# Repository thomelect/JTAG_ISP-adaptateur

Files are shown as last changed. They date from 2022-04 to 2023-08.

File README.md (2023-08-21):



<div align="center">
<h3 align="center">&#9889; Adaptateur JTAG vers ISP &#9889;</h3>
<a href="docs/img/JTAG_ISP-t.png">
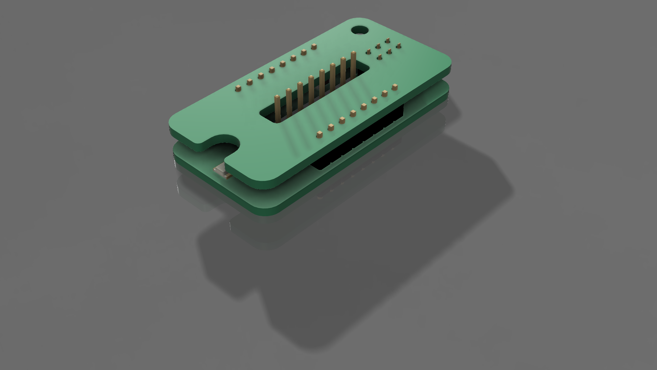
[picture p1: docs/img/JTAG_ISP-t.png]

</a>
<a href="docs/img/JTAG_ISP-b.png">
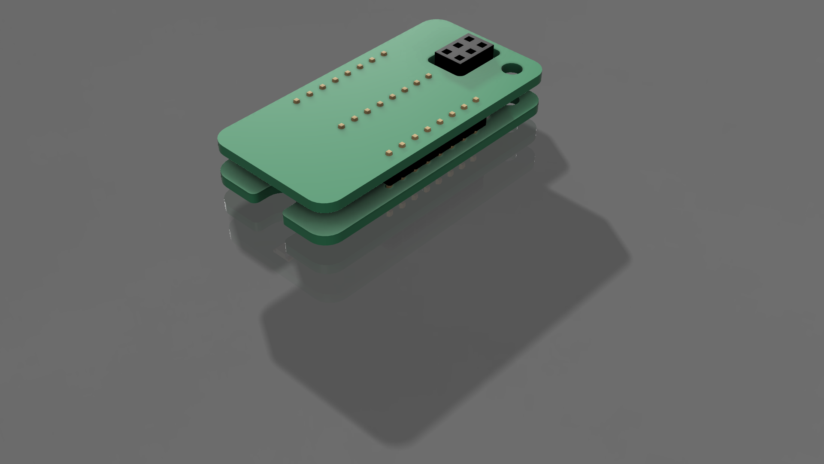
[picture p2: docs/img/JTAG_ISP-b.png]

</a>
<br>
<br>
<p align="center">Adaptateur compact utilisé pour connecteur un <a href="https://www.microchip.com/en-us/development-tool/PG164140">PICkit4 (JTAG)</a> au Arduino micro (ISP).</p>
</div>

<!-- TABLE DES MATIÈRES -->

---

<details>
<summary>Table des matières</summary>
<ol>
    <li>
        <a href="#apropos">À propos</a>
        <ul>
            <li><a href="#creation">Création</a></li>
            <ul>
                <li><a href="#creation_logiciels">Logiciels</a></li>
                <li><a href="#creation_fabrication-pcb">Fabrication PCB</a></li>
            </ul>
        </ul>
    </li>
    <li>
        <a href="#pour-debuter">Pour débuter</a>
        <ul>
            <li><a href="#prerequis">Prérequis</a>
            <ul>
                <li><a href="#prerequis_outils">Outils</a></li>
                <li><a href="#prerequis_bom">BOM</a></li>
            </ul>
            <li><a href="#assemblage">Assemblage</a></li>
        </ul>
    </li>
    <li><a href="#utilisation">Utilisation</a></li>
    <li><a href="#licence">Licence</a></li>
    <li><a href="#contacts">Contacts</a></li>
    <li><a href="#ressources">Ressources</a></li>
    <li><a href="#modele-readme">Modèle README</a></li>
</ol>
</details>

---

<!-- À-PROPOS -->

## À propos

Ce produit est utilisé pour programmer un microcontrôleur AVR avec un [PICkit4](https://www.microchip.com/en-us/development-tool/PG164140) sans l'utiliser connecté par JTAG. Il es alors possible d'utiliser le PICkit4 comme un [AVRISP MKII](https://www.microchip.com/en-us/development-tool/ATAVRISP2). Bien que l'utilisation du PICkit4 connecté en JTAG est utile pour le débogage des microcontrôleurs, lorsque le but est seulement de programmer et non de déboguer, il est plus rapide d'utiliser l'ISP puisque la connexion que requiert la connexion par JTAG nécessite plus de manipulations. Ce projet d'adaptateur parmet d'éviter l'utilisation de fils comme interface entre le PICkit4 et le microcontrôleur.

<p align="right">(<a href="#top">Haut de la page</a>)</p>

---

<!-- CRÉATION -->

### Création

- #### Logiciels

<ul>
<i><strong>👉 Design PCB</strong></i>
<ul>
<li>
<a href="https://www.kicad.org/">KiCad</a>
</li>
</ul>
<i><strong>👉 Export Fusion 360</strong></i>
<ul>
<li>
<a href="https://www.freecadweb.org/">FreeCAD</a>
</li>
<li>
<a href="https://wiki.freecadweb.org/KicadStepUp_Workbench/it">KiCad StepUp</a>
</li>
</ul>
<i><strong>👉 Rendu 3D</strong></i>
<ul>
<li>
<a href="https://www.autodesk.ca/fr/products/fusion-360">Fusion 360</a>
</li>
</ul>
</ul>

- #### Fabrication PCB

    - [PCBWay](https://www.pcbway.com/)
    - [JLCPSB](https://jlcpcb.com/)

<p align="right">(<a href="#top">Haut de la page</a>)</p>

---

<!-- POUR DÉBUTER -->

## Pour débuter

Les deux PCB ont été créés dans deux projets KiCad séparés. JTAG_ISP-ISP contient la partie du projet sur lequel le connecteur ISP est soudé alors que JTAG_ISP-HDR contient la partie du projet sur lequel le connecteur JTAG est soudé. Les deux PCB sont contenus dans le projet JTAG_ISP-BOTH.

<p align="right">(<a href="#top">Haut de la page</a>)</p>

---

<!-- PRÉREQUIS -->

### Prérequis

- #### Outils

  - [WE1010;](https://www.weller-tools.com/we1010na/)
  - [OMNIFIXO](https://omnifixo.com/)

- #### BOM

<table>
<tr>
<th><i>Adaptateur PinOut</i></th>
</tr>
<tr>
<td>

| Qty | Reference(s) | Value |
| :-: | :--- | --- |
|  1  | C1 | 100nF |
|  1  | J1 | PinSocket_2x03_P2.54mm |
|  2  | J2, J3 | PinHeader_1x08_P2.54mm |

</td>
</tr>
</table>
<table>
<tr>
<th><i>Adaptateur PinOut</i></th>
</tr>
<tr>
<td>

| Qty | Reference(s) | Value |
| :-: | :--- | --- |
|  1  | C1 | 100nF |
|  1  | D1 | LED |
|  2  | J1, J2 | PinSocket_2x03_P2.54mm |
|  1  | JTAG1 | PinHeader_1x08_P2.54mm |
|  1  | R1 | 100R |

</td>
</tr>
</table>

<p align="right">(<a href="#top">Haut de la page</a>)</p>

---

<!-- ASSEMBLAGE -->

### Assemblage

Il est seulement nécessaire de souder ensemble les composants sur le bon PCB et l'adaptateur est prêt à être utilisé!

<p align="right">(<a href="#top">Haut de la page</a>)</p>

---

<!-- UTILISATION -->

## Utilisation

Ce produit est utilisé pour programmer un microcontrôleur AVR avec un PICkit4 sans avoir à l'utiliser en le connectant par JTAG. Connectez simplement l'adapteteur sur le microcontrôleur et connectez ensuite le PICkit4 à l'adaptateur!

<table>
<tr>
<th><i>ISP sans adaptateur</i></th>
<th><i>ISP avec adaptateur</i></th>
</tr>
<tr>
<td>
<a href="docs/img/utilisationAvant.jpg">
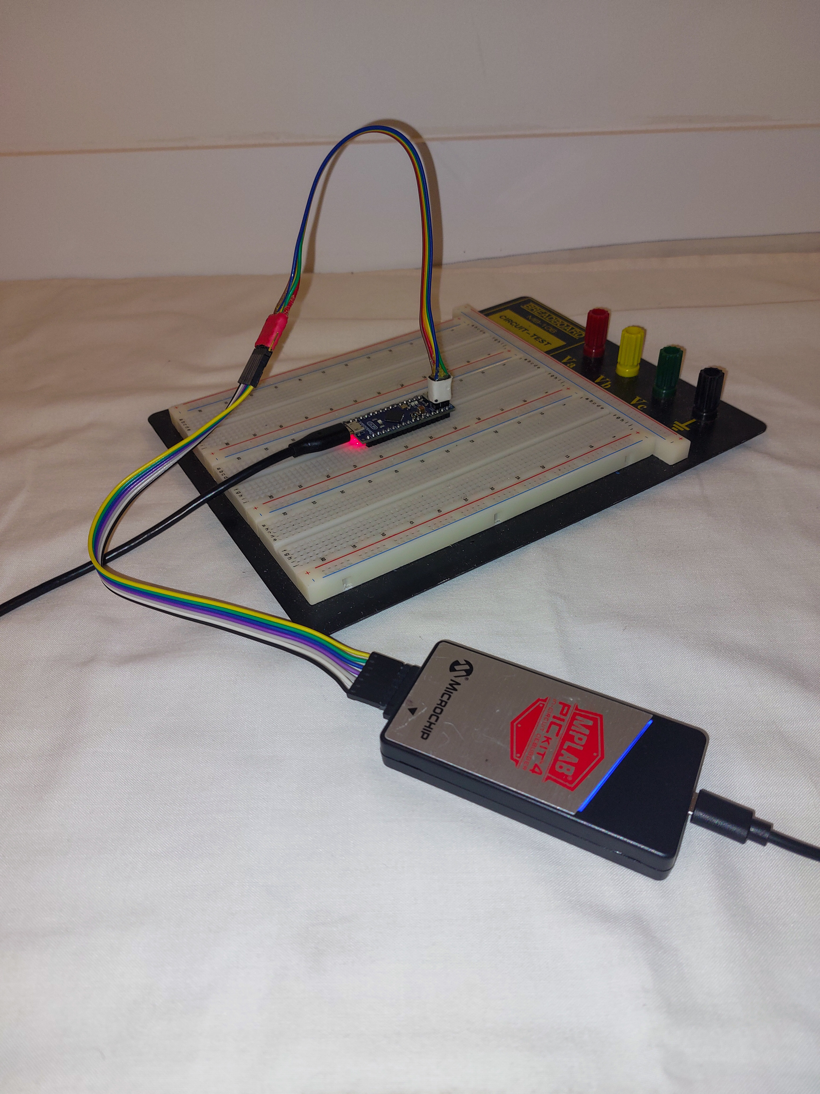
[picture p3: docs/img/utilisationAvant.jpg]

</a>
</td>
<td>
<a href="docs/img/utilisationApres.jpg">
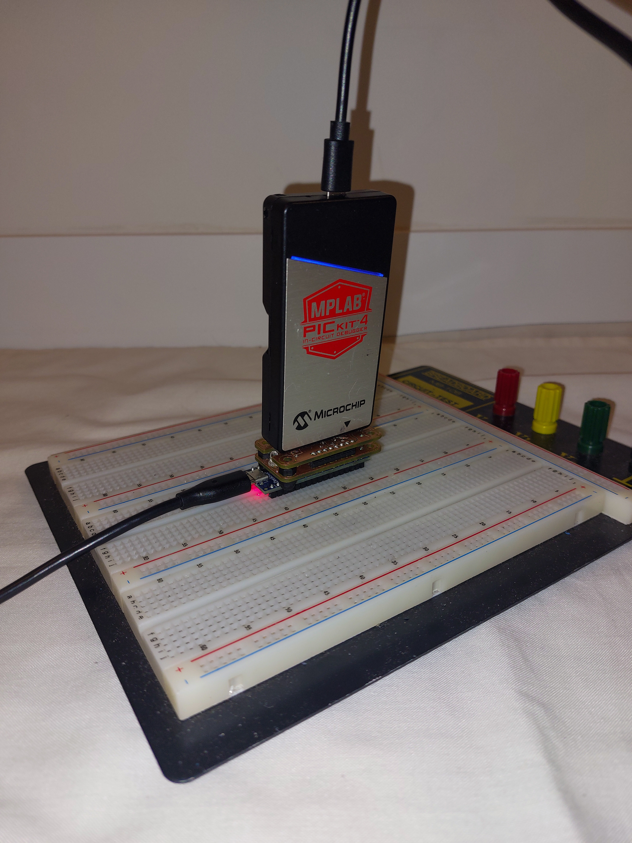
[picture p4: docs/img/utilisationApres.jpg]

</a>
</td>
</tr>
</table>

<p align="right">(<a href="#top">Haut de la page</a>)</p>

---

<!-- LICENCE -->

## Licence

Copyright 2022 Thomas Desrosiers

Licensed under the Apache License, Version 2.0 (the "License");
you may not use this file except in compliance with the License.
You may obtain a copy of the License at

       http://www.apache.org/licenses/LICENSE-2.0

Unless required by applicable law or agreed to in writing, software
distributed under the License is distributed on an "AS IS" BASIS,
WITHOUT WARRANTIES OR CONDITIONS OF ANY KIND, either express or implied.
See the License for the specific language governing permissions and
limitations under the License.

<p align="right">(<a href="#top">Haut de la page</a>)</p>

---

<!-- CONTACTS -->

## Contacts

<ul>
<i><strong>👉 GitHub</strong></i>
<ul>
<li>
<a href="https://github.com/thomelect" style="vertical-align:middle">thomelect</a>
</li>
<li>
<a href="https://github.com/thomelect/JTAG_ISP-adaptateur/" style="vertical-align:middle">Projet lumiereGarage</a>
</li>
</ul>
</ul>

<p align="right">(<a href="#top">Haut de la page</a>)</p>

---

<!-- RESSOURCES -->

## Ressources

<details>
<summary>PinOut</summary>
<table>
<tr>
<th><i>PICkit4</i></th>
<th><i>JTAP PinOut</i></th>
<th><i>ARDUINO ISP PinOut
<i></th>
</tr>
<tr>
<td>

<table>
<tr>
<th>Pin #</th>
<th>PICkit4</th>
</tr>
<tr>
<td>1</td>
<td>Vpp/NMCLR</td>
</tr>
<tr>
<td>2</td>
<td>VDD</td>
</tr>
<tr>
<td>3</td>
<td>GND</td>
</tr>
<tr>
<td>4</td>
<td>PGD</td>
</tr>
<tr>
<td>5</td>
<td>PGC</td>
</tr>
<tr>
<td>6</td>
<td>AUX</td>
</tr>
<tr>
<td>7</td>
<td>TDI</td>
</tr>
<tr>
<td>8</td>
<td>TMS</td>
</tr>
</table>

</td>
<td>

<table style="vertical-align:top">
<tr>
<th>Pin #</th>
<th>JTAG</th>
</tr>
<tr>
<td>1</td>
<td>-</td>
</tr>
<tr>
<td>2</td>
<td>VDD</td>
</tr>
<tr>
<td>3</td>
<td>GND</td>
</tr>
<tr>
<td>4</td>
<td>TDO</td>
</tr>
<tr>
<td>5</td>
<td>TCK</td>
</tr>
<tr>
<td>6</td>
<td>NRESET</td>
</tr>
<tr>
<td>7</td>
<td>TDI</td>
</tr>
<tr>
<td>8</td>
<td>TMS</td>
</tr>
</table>

</td>
<td>

<table>
<tr>
<th>Pin #</th>
<th>ISP</th>
</tr>
<tr>
<td>1</td>
<td>CIPO (MISO)</td>
</tr>
<tr>
<td>2</td>
<td>VCC</td>
</tr>
<tr>
<td>3</td>
<td>SCK</td>
</tr>
<tr>
<td>4</td>
<td>COPI (MOSI)</td>
</tr>
<tr>
<td>5</td>
<td>RESET</td>
</tr>
<tr>
<td>6</td>
<td>GND</td>
</tr>
</table>

</td>
</tr>
</table>
<table>
<tr>
<th><i>Adaptateur PinOut</i></th>
</tr>
<tr>
<td>

<table>
<tr>
<th>Pin #</th>
<th>JTAG</th>
<th>ISP</th>
</tr>
<tr>
<td>1</td>
<td>-</td>
<td>-</td>
</tr>
<tr>
<td>2</td>
<td>VDD</td>
<td>VCC</td>
</tr>
<tr>
<td>3</td>
<td>GND</td>
<td>GND</td>
</tr>
<tr>
<td>4</td>
<td>TDO</td>
<td>CIPO (MISO)</td>
</tr>
<tr>
<td>5</td>
<td>TCK</td>
<td>SCK</td>
</tr>
<tr>
<td>6</td>
<td>NRESET</td>
<td>RESET#</td>
</tr>
<tr>
<td>7</td>
<td>TDI</td>
<td>COPI (MOSI)</td>
</tr>
<tr>
<td>8</td>
<td>TMS</td>
<td>-</td>
</tr>
</table>

</td>
</tr>
</table>
</details>

<ul>
<li>
<a href="https://docs.arduino.cc/static/59994142e99a42eea5731bf61b08922b/A000053-full-pinout.pdf"
style="vertical-align:middle">Arduino Micro PinOut (Le PinOut est le même pour tout les Arduino).</a>
</li>
<li>
<a href="http://ww1.microchip.com/downloads/en/devicedoc/50002721a.pdf" style="vertical-align:middle">PICkit4
Quick Start Guide.</a>
</li>
</ul>

<p align="right">(<a href="#top">Haut de la page</a>)</p>

---

<!-- MODÈLE README -->

## Modèle README

<a href="https://github.com/othneildrew/Best-README-Template/blob/master/BLANK_README.md">`Template README`</a>

<p align="right">(<a href="#top">Haut de la page</a>)</p>

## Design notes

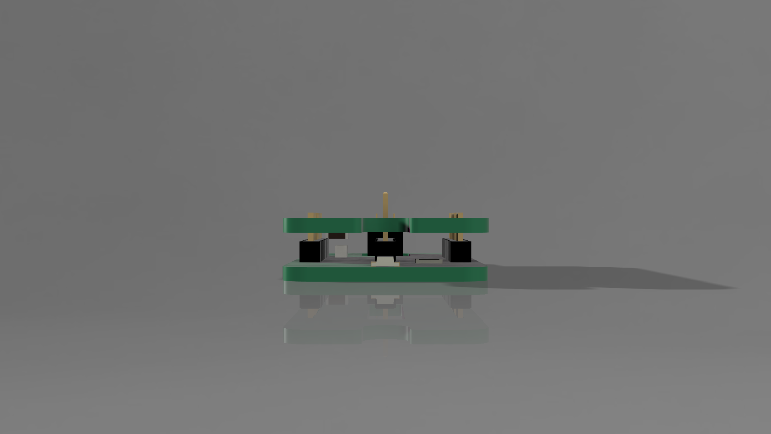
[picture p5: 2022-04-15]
docs/img/JTAG_ISP-f.png

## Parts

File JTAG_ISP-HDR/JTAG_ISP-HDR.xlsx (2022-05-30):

Item | Qty | Reference(s) | Value | LibPart | Footprint | Datasheet
1 | 1 | C1 | 100nF | Device:C | Capacitor_SMD:C_1206_3216Metric_Pad1.33x1.80mm_HandSolder | ~
2 | 1 | D1 | LED | Device:LED | LED_SMD:LED_1210_3225Metric_Pad1.42x2.65mm_HandSolder | ~
3 | 2 | J1, J2 | Conn_01x08 | Connector_Generic:Conn_01x08 | Connector_PinHeader_2.54mm:PinHeader_1x08_P2.54mm_Vertical | ~
4 | 1 | JTAG1 | PICkit4 | THOMAS_library:PICkit4 | THOMAS_library:PicKit4-2
5 | 1 | R1 | 100 | Device:R_US | Resistor_SMD:R_1206_3216Metric_Pad1.30x1.75mm_HandSolder | ~

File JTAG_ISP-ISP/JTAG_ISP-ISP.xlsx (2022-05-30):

Item | Qty | Reference(s) | Value | LibPart | Footprint | Datasheet
1 | 1 | C1 | 100nF | Device:C | Capacitor_SMD:C_1206_3216Metric_Pad1.33x1.80mm_HandSolder | ~
2 | 1 | J1 | Conn_02x03_Odd_Even | Connector_Generic:Conn_02x03_Odd_Even | Connector_PinSocket_2.54mm:PinSocket_2x03_P2.54mm_Vertical | ~
3 | 2 | J2, J3 | Conn_01x08 | Connector_Generic:Conn_01x08 | Connector_PinHeader_2.54mm:PinHeader_1x08_P2.54mm_Vertical | ~

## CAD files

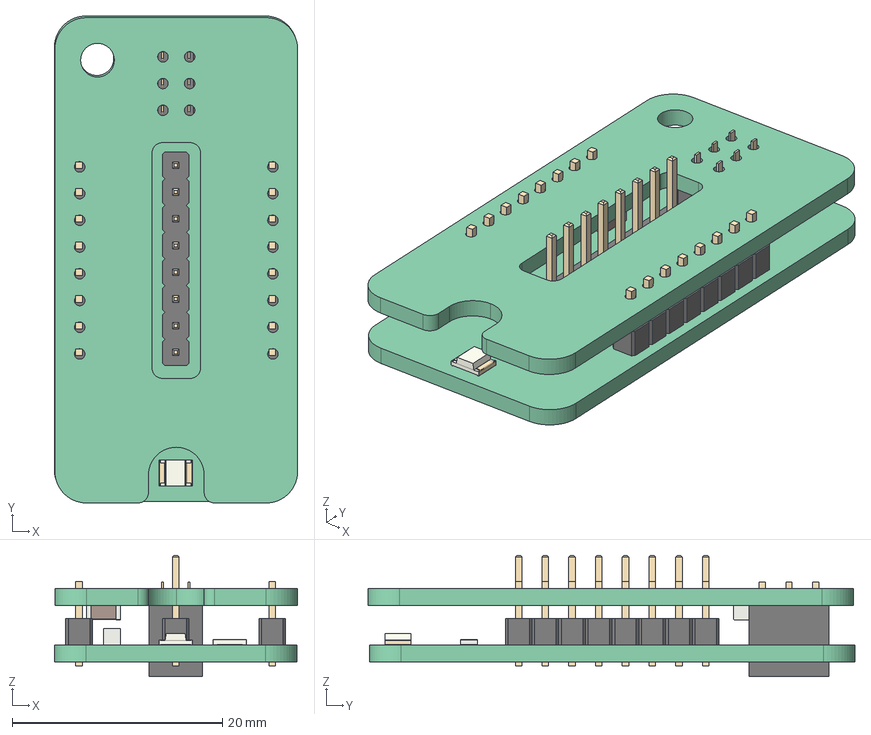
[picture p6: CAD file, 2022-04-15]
docs/3d/JTAG_ISP-3d.step
23.1 x 46.3 x 11.5 mm
Pcb_b0ad
C1_C_1206_3216Metric_8ab35eb3909b
J1_PinSocket_2x03_P254mm_Vertical_11958836bf48
Pcb_3d3b
J2_PinHeader_1x08_P254mm_Vertical_fe993c246832
C1_C_1206_3216Metric_07f5eb895435
J1_PinHeader_1x08_P254mm_Vertical_b79930fb2714
JTAG1_PinHeader_1x08_P254mm_Vertical_10c12ca8a28d
D1_LED_1210_3225Metric_053afcd77527
R1_R_1206_3216Metric_2292a632100f

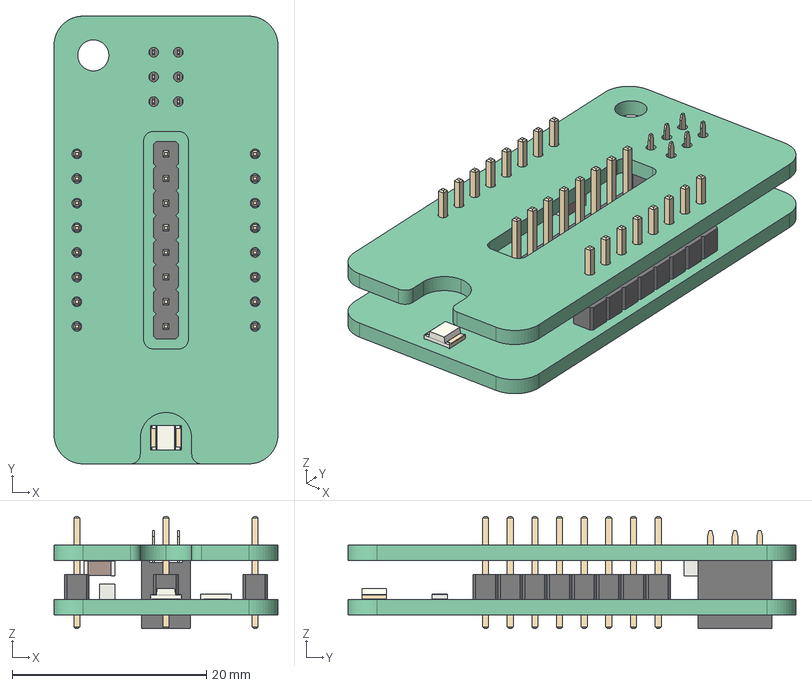
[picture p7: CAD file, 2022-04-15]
docs/3d/JTAG_ISP_3d-base.step
23.1 x 46.1 x 11.5 mm
Pcb_b0ad
C1_C_1206_3216Metric_8ab35eb3909b
J1_PinSocket_2x03_P254mm_Vertical_11958836bf48
Pcb_3d3b
J2_PinHeader_1x08_P254mm_Vertical_fe993c246832
C1_C_1206_3216Metric_07f5eb895435
J1_PinHeader_1x08_P254mm_Vertical_b79930fb2714
JTAG1_PinHeader_1x08_P254mm_Vertical_10c12ca8a28d
D1_LED_1210_3225Metric_053afcd77527
R1_R_1206_3216Metric_2292a632100f

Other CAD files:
docs/3d/JTAG_ISP_3d-base.FCStd

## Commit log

2022-03-15 + Création des deux PCB dans des projets séparés. + Ajout d'un projet dans lequel les deux PCB sont joints. **Le circuit pour l'étage ISP est à vérifier**
    [JTAG_ISP-HDR.kicad_pcb, JTAG_ISP-HDR.kicad_sch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]
2022-03-15 + Ajout d'un trou sur chacun des 2 PCB pour pouvoir y fixer une dragone. + Ajout d'un espace de texte contenant mon nom et la date sur le PCB ISP. + Ajout d'un dossier contenant les fichiers générés 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
    [JTAG_ISP-HDR-B_Cu.gbl, JTAG_ISP-HDR-B_Cu.gbr, JTAG_ISP-HDR-Edge_Cuts.gbr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]
2022-03-15 # [PCB] ~ Modification du PCB pour le projet ISP en fonction des nouvelles connexions sur son schéma. + Ajout de trous aux 4 coins du PCB des 2 projets (ISP & HDR). ~ Augmentation de la taille du PCB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
    # [SCHÉMA]
    ~ Modification du schéma pour le projet ISP basé sur le fil JTAG -> ISP déjà existant.
    + Ajout de texte sur le schéma des 2 projets indiquant le nom des broches sur les headers.
    [JTAG_ISP-HDR-B_Cu.gbl, JTAG_ISP-HDR-B_Cu.gbr, JTAG_ISP-HDR-Edge_Cuts.gbr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]
2022-03-15 + Ajout d'un projet dans lequel les deux PCB sont joints.
    # [PCB]
    + Ajout d'une DEL et de sa résistance en fonction des nouvelles connexions sur son schéma.
    ~ Déplacement du header ISP sur le côté dans le projet ISP afin de moins empiéter sur les circuits autour lorsque le shied est utilisé sur un MCU.
    ~ Rotation du header ISP pour être plus facilement connecté au MCU.
    + Ajout d'une DEL et de sa résistance sur le broche MISO pour pour pouvoir voir quand est-ce qu'une programmation se fait.
    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
    [JTAG_ISP-BOTH.kicad_pcb, JTAG_ISP-BOTH.kicad_sch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]
2022-03-15 - Abandon de la panélisation puisque son utilisation n'est pas pertinante et trop compliquée.
    [JTAG_ISP-HDR-B_Cu.gbl, JTAG_ISP-HDR-Edge_Cuts.gko, JTAG_ISP-HDR-F_Cu.gtl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]
2022-03-16 # [PCB] ~ Augmentation de la largeur des traces et du dégagement des traces à 20 mils.
    [JTAG_ISP-HDR.kicad_pcb, JTAG_ISP-ISP.kicad_pcb]
2022-03-16 # [PCB] + Ajout d'un trou au bas du PCB pour le projet du projet HDR pour laisser passer la sur le PCB d'en dessous. - Suppression du texte (nom & date) sur le PCB du bas puisqu'il ne sera pas le plu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
    [JTAG_ISP-HDR.kicad_pcb, JTAG_ISP-ISP.kicad_pcb]
2022-03-16 # [PCB] ~ Modification du texte (initiales et date du jours) sur le PCB du projet HDR.
    [JTAG_ISP-HDR.kicad_pcb]
2022-03-16 ~ Mise à jour des 2 PCB dans le projet BOTH qui est utilisé pour combiner les projets ISP et HDR pour la fabrication.
    [JTAG_ISP-BOTH.kicad_pcb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]
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2022-03-17 # [PCB] ~ Modification du texte (date du jour) sur le PCB du projet HDR.
    ~ Alignement du texte sur le schéma des 2 projets indiquant le nom des broches sur les headers.
    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
    [JTAG_ISP-HDR.kicad_pcb, JTAG_ISP-HDR.kicad_sch, JTAG_ISP-ISP.kicad_sch]
2022-03-17 # [PCB] + Ajout d'un trou dans le haut du PCB du projet HDR pour pouvoir y fixer une dragone. ~ Modification de l'empreinte du JTAG. - Non affichage des référence pour les trous et les flèches sur le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
    [JTAG_ISP-HDR.kicad_pcb, JTAG_ISP-ISP.kicad_pcb]
2022-03-17 # [PCB] + Ajout d'un encavure dans le haut du PCB du projet HDR pour que la dragone ne dépasse pas sur le bord du PCB. - Suppression du fichier .round-tracks-config qui est inutile. * Mise à jours de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
    * Mise à jours de la cartouche pour les 2 projets.
    * Date actuelle.
    * Version actuelle.
    * Titre du projet.
    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
    [JTAG_ISP-HDR.kicad_pcb, JTAG_ISP-HDR.kicad_sch, JTAG_ISP-ISP.kicad_pcb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]
2022-03-17 # [PCB] * Mise à jour des fichiers gerbers du projet BOTH. + Création d'une archive PROD_LPKF.zip qui contient les fichiers envoyés pour fabrication. - Suppression du fichier .round-tracks-config qui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
    [JTAG_ISP-BOTH.kicad_pcb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]
2022-03-18 # [SCHÉMA] * Correction mauvaise numérotation de broche sur le header J1 du projet ISP. * Mise à jours de la cartouche pour les 2 projets. * Date actuelle; * Version actuelle; * Titre du projet.
    [JTAG_ISP-HDR.kicad_sch, JTAG_ISP-ISP.kicad_sch]
2022-03-18 # [PCB] * Correction mauvaise numérotation de broche sur le header J1 du projet ISP. * Correction de mauvaise couche pour les piste du condo C1 et de la DEL D1 du projet ISP. * Projet ISP routé à nou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
    * Correction mauvaise numérotation de broche sur le header J1 du projet ISP.
    + Ajout de GND et de VCC dans le projet ISP sur les broches non utilisés de J2 & J3.
    + Ajout des nouveaux nom de broche sur J2 & J3.
    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
    [JTAG_ISP-HDR.kicad_pcb, JTAG_ISP-HDR.kicad_sch, JTAG_ISP-ISP.kicad_pcb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]
2022-03-19 # [PCB] + Ajout de GND et de VCC dans le projet HDR sur les broches non utilisés de J1 & J2. + Ajout des nouveaux vias. * Projet HDR routé à nouveau. * Utilisation de trous de montage avec pads. * Fl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
    + Ajout de GND et de VCC dans le projet HDR sur les broches non utilisées de J1 & J2.
    + Ajout des nouveaux noms de broches sur J1 & J2.
    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
    [JTAG_ISP-HDR.kicad_pcb, JTAG_ISP-HDR.kicad_sch]
2022-03-19 # [PCB] + Création d'une archive PROD_LPKF.zip qui contient les fichiers envoyés pour fabrication. * Mise à jour des fichiers gerbers du projet BOTH. * Mise à jour de la cartouche pour le projet BOTH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
    - Suppression du fichier de schéma puisque ce projet est utilisé seulement pour combiner les 2 PCB.
    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
    [JTAG_ISP-BOTH.kicad_pcb, JTAG_ISP-BOTH.kicad_sch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]
2022-03-19 # Version compacte en cours... ## Les headers passent à travers d'un PCB et dépassent moins que la version précédente.
    + Ajout d'un trou pour l'ISP dans le PCB du projet HDR.
    + Ajout d'un trou pour le PICkit dans le PCB du projet ISP.
    * Déplacement du circuit de DEL dans le projet HDR.
    * Projet ISP routé à nouveau.
    * Mise à jour de la cartouche pour les 2 projets.
    * Date actuelle;
    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
    [JTAG_ISP-HDR.kicad_pcb, JTAG_ISP-HDR.kicad_sch, JTAG_ISP-ISP.kicad_pcb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]
2022-03-20 # [PCB] + Ajout du dégagement de 40 mils sur la bordure du trou au centre du PCB et sur le pourtour. [ISP] + Ajout du texte (date du jour) dans le bas du PCB. [ISP] + Ajout de la flèche indiquand la 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
    * Mise à jour de la cartouche. [ISP]
    * Nouveau format de page A5.
    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
    [JTAG_ISP-ISP.kicad_pcb, JTAG_ISP-ISP.kicad_sch]
2022-03-21 # [PCB] + Ajout de vias pour assurer la bonne connexion du ground. [ISP] * Correction trace RESET sur mauvaise couche. [ISP] * Modification du texte. [ISP] * Date du jour; + Version actuelle. * Mise 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
    [JTAG_ISP-ISP.kicad_pcb, JTAG_ISP-ISP.kicad_sch]
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2022-05-30 # [SCHÉMA] + Ajout des bon noms de footprint pour les pièces SMD pour concorder avec celle du PCB. + Ajout de BOM pour les 2 PCB. * Correction de la cartouche; * Version actuelle.
    [JTAG_ISP-HDR-B_Cu.gbr, JTAG_ISP-HDR-B_Mask.gbr, JTAG_ISP-HDR-B_Silkscreen.gbr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]
